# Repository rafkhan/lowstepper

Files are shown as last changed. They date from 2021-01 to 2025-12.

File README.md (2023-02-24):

# Lowstepper
```
██      ██████  ██     ██ ███████ ████████ ███████ ██████  ██████  ███████ ██████  
██     ██    ██ ██     ██ ██         ██    ██      ██   ██ ██   ██ ██      ██   ██ 
██     ██    ██ ██  █  ██ ███████    ██    █████   ██████  ██████  █████   ██████  
██     ██    ██ ██ ███ ██      ██    ██    ██      ██      ██      ██      ██   ██ 
███████ ██████   ███ ███  ███████    ██    ███████ ██      ██      ███████ ██   ██ 
                                                                                   

                  AN OPEN SOURCE EURORACK MODULE CREATED BY
 
      ▄ •▄  ▄▄▄· ▄· ▄▌.▄▄ ·  ▄· ▄▌ ▐ ▄ ▄▄▄▄▄ ▄ .▄▄▄▄ ..▄▄ · ▪  ·▄▄▄▄•▄▄▄ .▄▄▄  
▪     █▌▄▌▪▐█ ▀█▐█▪██▌▐█ ▀. ▐█▪██▌•█▌▐█•██  ██▪▐█▀▄.▀·▐█ ▀. ██ ▪▀·.█▌▀▄.▀·▀▄ █·
 ▄█▀▄ ▐▀▀▄·▄█▀▀█▐█▌▐█▪▄▀▀▀█▄▐█▌▐█▪▐█▐▐▌ ▐█.▪██▀▐█▐▀▀▪▄▄▀▀▀█▄▐█·▄█▀▀▀•▐▀▀▪▄▐▀▀▄ 
▐█▌.▐▌▐█.█▌▐█ ▪▐▌▐█▀·.▐█▄▪▐█ ▐█▀·.██▐█▌ ▐█▌·██▌▐▀▐█▄▄▌▐█▄▪▐█▐█▌█▌▪▄█▀▐█▄▄▌▐█•█▌
 ▀█▄▀▪·▀  ▀ ▀  ▀  ▀ •  ▀▀▀▀   ▀ • ▀▀ █▪ ▀▀▀ ▀▀▀ · ▀▀▀  ▀▀▀▀ ▀▀▀·▀▀▀ • ▀▀▀ .▀  ▀
```

LowStepper, a synth module by [Okay Synthesizer](https://okaysynthesizer.com/) <3

# LICENSE

This program is free software: you can redistribute it and/or modify
it under the terms of the GNU General Public License as published by
the Free Software Foundation, either version 3 of the License, or
(at your option) any later version.

This program is distributed in the hope that it will be useful,
but WITHOUT ANY WARRANTY; without even the implied warranty of
MERCHANTABILITY or FITNESS FOR A PARTICULAR PURPOSE.  See the
GNU General Public License for more details.

You should have received a copy of the GNU General Public License
along with this program.  If not, see <https://www.gnu.org/licenses/>.

------

Look, if you're considering selling this... go for it, but we would rather you call us up and collaborate. If you are going to sell it, please make your files available for the community to build on. That's all we ask :)

------

Maintained, with love, by [Okay Synthesizer](https://okaysynthesizer.com/) <3

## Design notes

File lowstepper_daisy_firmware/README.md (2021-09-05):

# lowstepper_daisy_firmware

## Author

<!-- Insert Your Name Here -->

## Description

<!-- Describe your example here -->

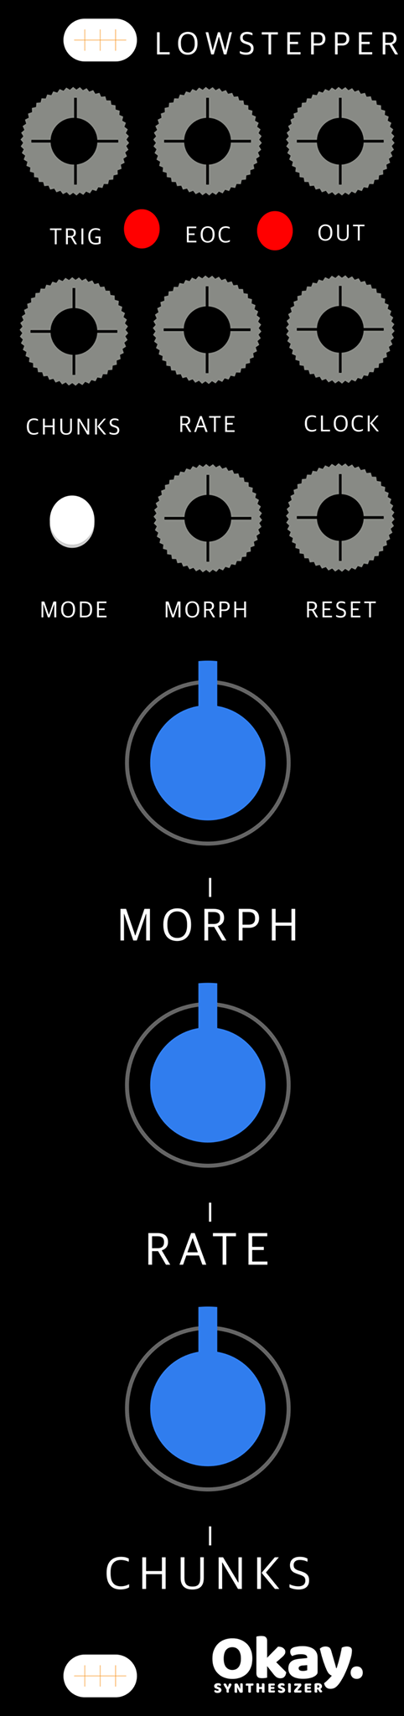
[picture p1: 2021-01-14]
lowstepper_wasm_demo/src/Lowstepper.png

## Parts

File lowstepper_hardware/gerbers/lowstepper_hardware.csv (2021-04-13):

Comment | Designator | Footprint | LCSC
1n | C2,C3,C4,C8,C9,C10 | Capacitor_SMD:C_0603_1608Metric_Pad1.08x0.95mm_HandSolder
47u | C1,C5 | Capacitor_SMD:C_0603_1608Metric_Pad1.08x0.95mm_HandSolder
10u | C6 | Capacitor_SMD:C_0603_1608Metric_Pad1.08x0.95mm_HandSolder
100n | C7 | Capacitor_SMD:C_0603_1608Metric_Pad1.08x0.95mm_HandSolder
XZM2CRKM2DGFBB45SCCB | D1,D2 | LED_XZM2CRKM2DGFBB45SCCB
Conn_01x20_Male | J18,J19 | Connector_PinHeader_2.54mm:PinHeader_1x20_P2.54mm_Vertical
Conn_01x20_Female | J20,J21 | Connector_PinSocket_2.54mm:PinSocket_1x20_P2.54mm_Vertical
PJ398SM-12 | J1,J2,J3,J4,J5,J6,J7,J9,J10,J11,J12,J13,J14,J15,J16,J17 | THONK_PJ398SM-12
Conn_02x08_Odd_Even | J8 | Connector_PinHeader_2.54mm:PinHeader_2x08_P2.54mm_Vertical
MMBT3904 | Q1,Q2,Q3,Q4,Q5,Q6 | Package_TO_SOT_SMD:SOT-23
470 | R16,R18,R47,R49 | Resistor_SMD:R_0603_1608Metric_Pad0.98x0.95mm_HandSolder
10K | R3,R7,R19,R34,R37,R40,R43,R46 | Resistor_SMD:R_0603_1608Metric_Pad0.98x0.95mm_HandSolder
1k | R2,R17,R48 | Resistor_SMD:R_0603_1608Metric_Pad0.98x0.95mm_HandSolder
10k | R20 | Resistor_SMD:R_0603_1608Metric_Pad0.98x0.95mm_HandSolder
3.3k | R1,R15,R21,R22,R32,R35,R38,R41,R44 | Resistor_SMD:R_0603_1608Metric_Pad0.98x0.95mm_HandSolder
100K | R4,R33,R36,R39,R42,R45 | Resistor_SMD:R_0603_1608Metric_Pad0.98x0.95mm_HandSolder
200k | R5,R9,R12,R23,R26,R29 | Resistor_SMD:R_0603_1608Metric_Pad0.98x0.95mm_HandSolder
100k | R6,R10,R13,R24,R27,R30 | Resistor_SMD:R_0603_1608Metric_Pad0.98x0.95mm_HandSolder
33k | R8,R11,R14,R25,R28,R31 | Resistor_SMD:R_0603_1608Metric_Pad0.98x0.95mm_HandSolder
10K | RV1,RV2,RV3,RV4,RV5,RV6 | Potentiometer_THT:Potentiometer_Alpha_RD901F-40-00D_Single_Vertical
SW_Push | SW1 | Button_Switch_SMD:SW_SPST_B3U-1000P
TL072 | U1 | Package_SO:SOIC-8_3.9x4.9mm_P1.27mm
MCP6004 | U2 | Package_SO:SOIC-14_3.9x8.7mm_P1.27mm
Teensy3.5 | U3 | teensy:Teensy35_36
LM4040DBZ-10 | U4 | Package_TO_SOT_SMD:SOT-23
MCP6002-xSN | U5,U6 | Package_SO:SOIC-8_3.9x4.9mm_P1.27mm

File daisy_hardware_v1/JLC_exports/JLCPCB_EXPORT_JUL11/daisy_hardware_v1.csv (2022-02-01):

Comment | Designator | Footprint | LCSC
47u | C1,C2 | Capacitor_SMD:CP_Elec_4x5.3
10u | C3,C13,C15 | Capacitor_SMD:CP_Elec_4x5.3
100n | C4,C14 | Capacitor_SMD:C_0603_1608Metric
1n | C5,C6,C7,C8,C9,C10,C11,C12 | Capacitor_SMD:C_0603_1608Metric
Conn_02x08_Odd_Even | J1 | Connector_PinHeader_2.54mm:PinHeader_2x08_P2.54mm_Vertical
PJ398SM-12 | J2,J3,J4,J5,J7,J8,J10,J11,J12,J13,J14,J15,J16,J17,J18,J19 | lowstepper_internal_footprint_lib:THONK_PJ398SM-12
Conn_01x18_Female | J20,J21 | Connector_PinSocket_2.54mm:PinSocket_1x18_P2.54mm_Vertical
Conn_01x18_Male | J6,J9 | Connector_PinHeader_2.54mm:PinHeader_1x18_P2.54mm_Vertical
MMBT3904 | Q2,Q3,Q5,Q6 | Package_TO_SOT_SMD:SOT-23
3.3k | R1,R2,R7,R9,R12,R18,R21 | Resistor_SMD:R_0603_1608Metric
100k | R10,R13,R19,R22,R25,R28,R31,R34,R37,R40,R43,R46 | Resistor_SMD:R_0603_1608Metric
200k | R24,R27,R30,R33,R36,R39,R42,R45 | Resistor_SMD:R_0603_1608Metric
33k | R26,R29,R32,R35,R38,R41,R44,R47 | Resistor_SMD:R_0603_1608Metric
10k | R3,R4,R6,R11,R14,R20,R23 | Resistor_SMD:R_0603_1608Metric
1k | R5 | Resistor_SMD:R_0603_1608Metric
10k | RV1,RV2,RV3,RV4,RV5,RV6,RV7,RV8 | Potentiometer_THT:Potentiometer_Alpha_RD901F-40-00D_Single_Vertical_CircularHoles
SW_SPDT | SW1,SW2 | lowstepper_internal_footprint_lib:dailywell_sw_spdt
RAF_DAISY_SEED_V1 | U1 | lowstepper_internal_footprint_lib:DAISY_SEED_OKAYSYNTH
LM1117-5.0 | U10 | Package_TO_SOT_SMD:SOT-223
TL072 | U2 | Package_SO:SOIC-8_3.9x4.9mm_P1.27mm
74HC4051 | U3,U4 | Package_SO:SOIC-16_3.9x9.9mm_P1.27mm
LM4040DBZ-10 | U5 | Package_TO_SOT_SMD:SOT-23
MCP6004 | U6,U7 | Package_SO:SO-14_3.9x8.65mm_P1.27mm
MCP6002-xSN | U8 | Package_SO:SOIC-8_3.9x4.9mm_P1.27mm
R-78E3.3-0.5 | U9 | Converter_DCDC:Converter_DCDC_RECOM_R-78E-0.5_THT

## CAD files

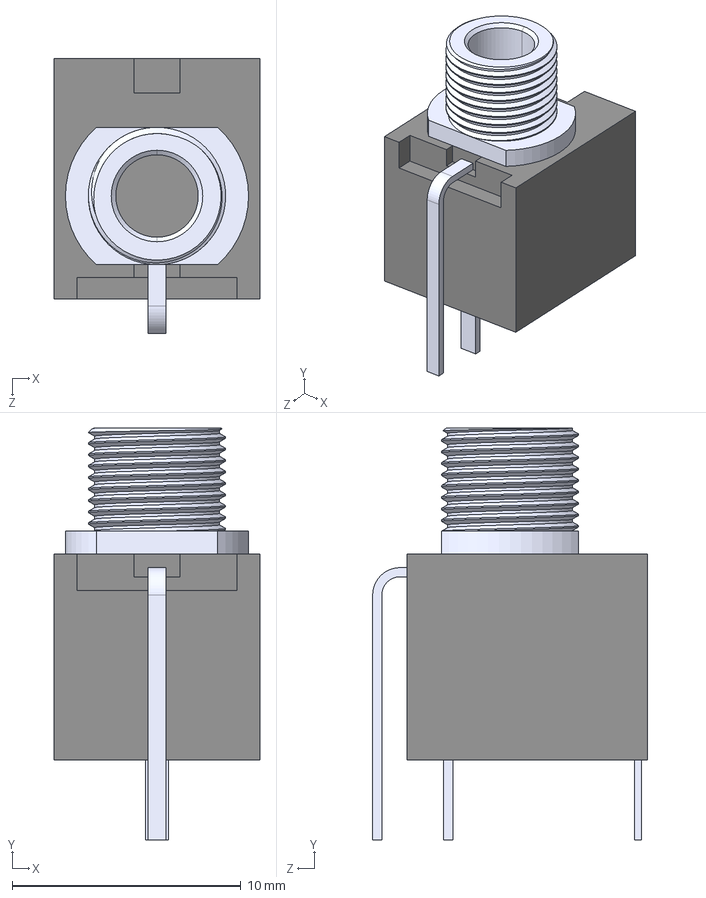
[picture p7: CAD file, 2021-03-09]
daisy_hardware_v1/external_libraries/PJ398SM-12/PJ398SM-12.step
9.00 x 18.0 x 12.0 mm

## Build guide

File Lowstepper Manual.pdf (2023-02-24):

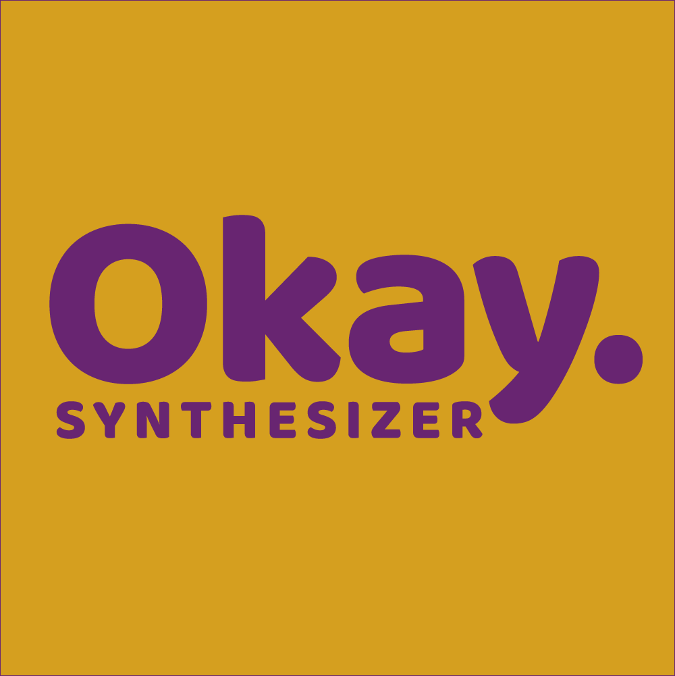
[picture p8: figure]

Hello, world.

Welcome to Okay Synthesizer, and thank you for purchasing a Lowstepper. It means the world to us to have you join the crew. We encourage you to do the maximum amount of damage possible with this module, and we promise that it is a substantial amount.

# Front Panel Overview

Both sides are identical, there are no normalled connections between them.

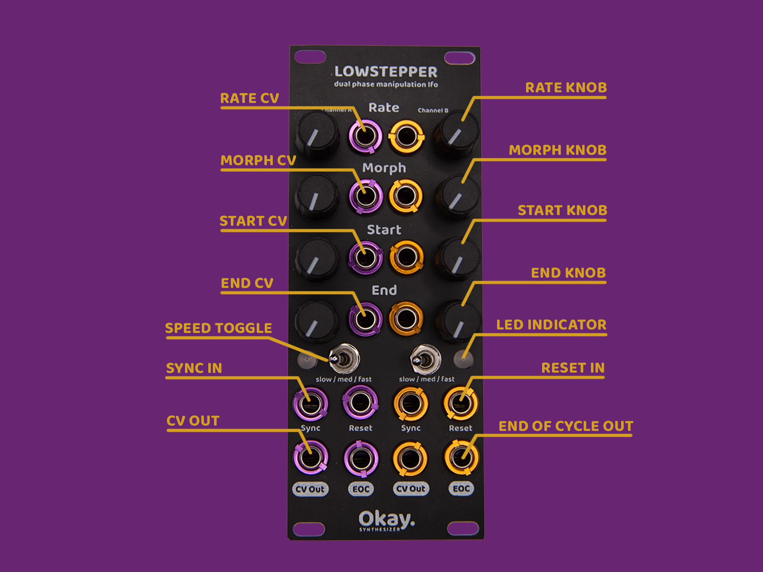
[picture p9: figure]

Rate: Change the speed of the LFO. The range of Rate changes based on the Speed Toggle. The rate will also change in fractional increments relative to the BPM, when sync is plugged in.

Morph: Warp the wave from sin, to triangle, to saw, to a slightly warped square.

Start: Move the start phase of the LFO from 0 - 100%. Will move in even increments when sync is plugged in.

End: Move the end phase of the LFO from 0 - 100%. Will move in even increments when sync is plugged in.

Speed Toggle: Switches between different ranges of speeds.

Sync In: Trigger input accepting 1/16th notes, will modify the behavior of Rate, Start and End when plugged in.

Reset In: Trigger input. Will instantly jump back to the start point of the LFO when a trigger is received.

CV Out: Main LFO output! Party time!

End of Cycle Out: Trigger output. Will output a trigger when the LFO reaches the end point.

# What the F**k is a “dual phase manipulation LFO” ?

I’m going to assume that you, the modular synthesizer owner, likely knows what an LFO is. It is a Low Frequency Oscillator. Which is described as an oscillator that moves below the frequency at which humans hear (20hz or so). In the case of Lowstepper, there are facilities for typical low frequency oscillations, as well as audible oscillations when Speed Toggle is set to Med or Fast.

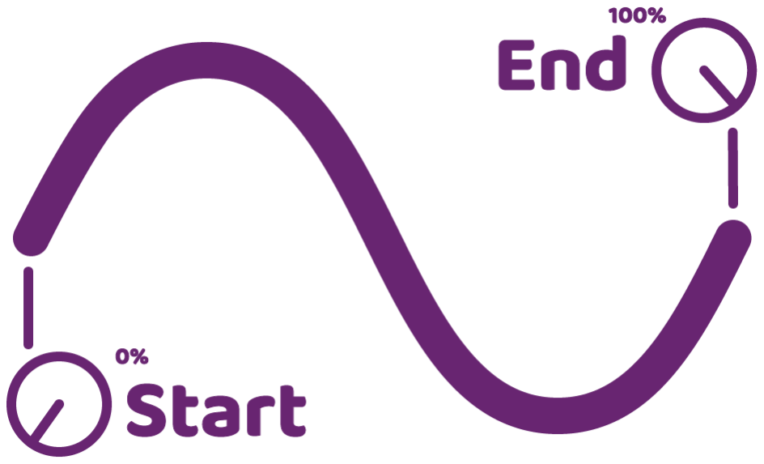
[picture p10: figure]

A completely unsuspecting sine wave….

The goal of lowstepper is to let you control the start and end position of a standard LFO
waveform, to create new wave shapes. You can push and pull the start and end points of the waves by turning the Start Knob and End Knob, and by using the corresponding Start CV and End CV controls beside them. When CV is passed into any controls, the knob acts as an offset.

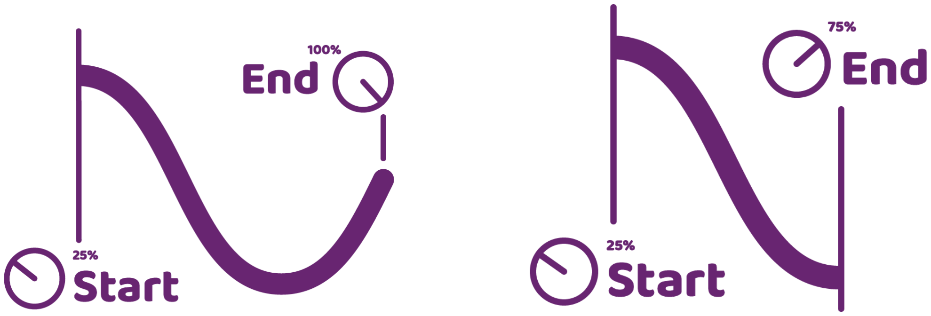
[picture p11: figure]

Left: Start point shifted 25%, end point left at 100% Right: Start and end point shifted to 25% and 75% respectively

When the end point is before the start, it will travel from the end to the start, effectively inverting the wave you started with

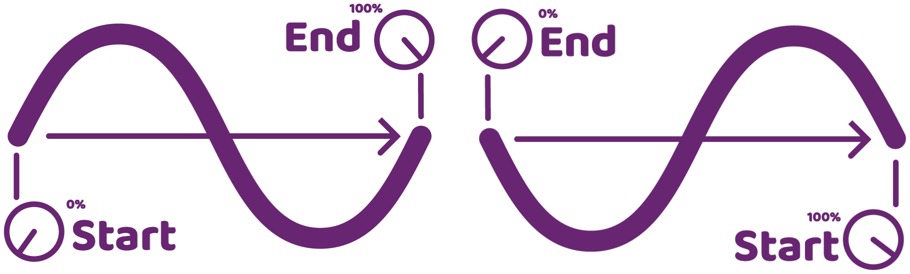
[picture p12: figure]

Left: Normal direction of travel Right: Inverted direction of travel

## Tech Specs

CV Output: 8v (-3.3 to 4.7 volts) the offset is intentional, so that the standard wave, and inverted wave shape is not 100% symmetrical, weird by design.
CV Inputs: +5v to -5v

EOC trigger output: +3.3v

## Firmware Update

Download the latest version of the firmware at https://okaysynthesizer.com/products/lowstepper in the Downloads section of the product description.

Visit https://electro-smith.github.io/Programmer/ and follow the on-screen instructions. Make sure you upload the correct firmware file from your computer before programming. Flashing the wrong firmware can result in unknown damages.

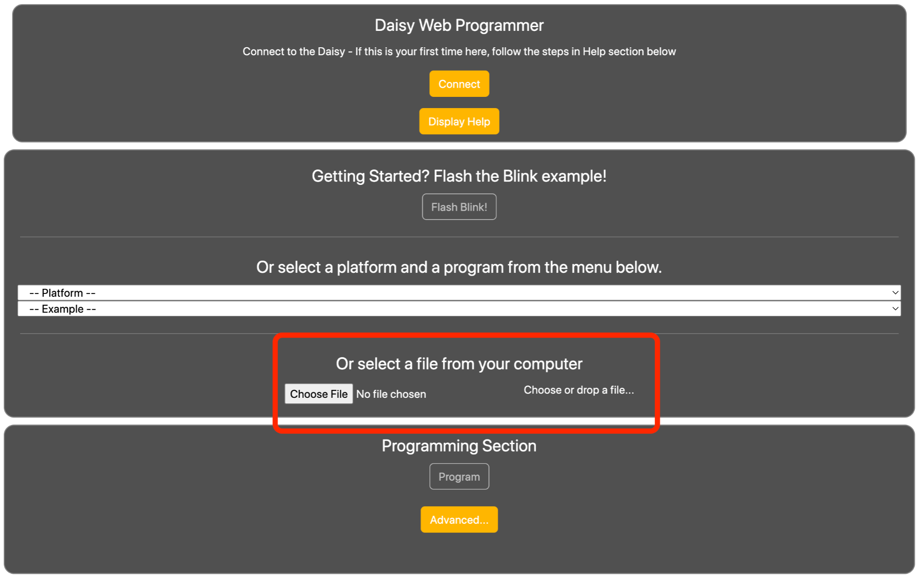
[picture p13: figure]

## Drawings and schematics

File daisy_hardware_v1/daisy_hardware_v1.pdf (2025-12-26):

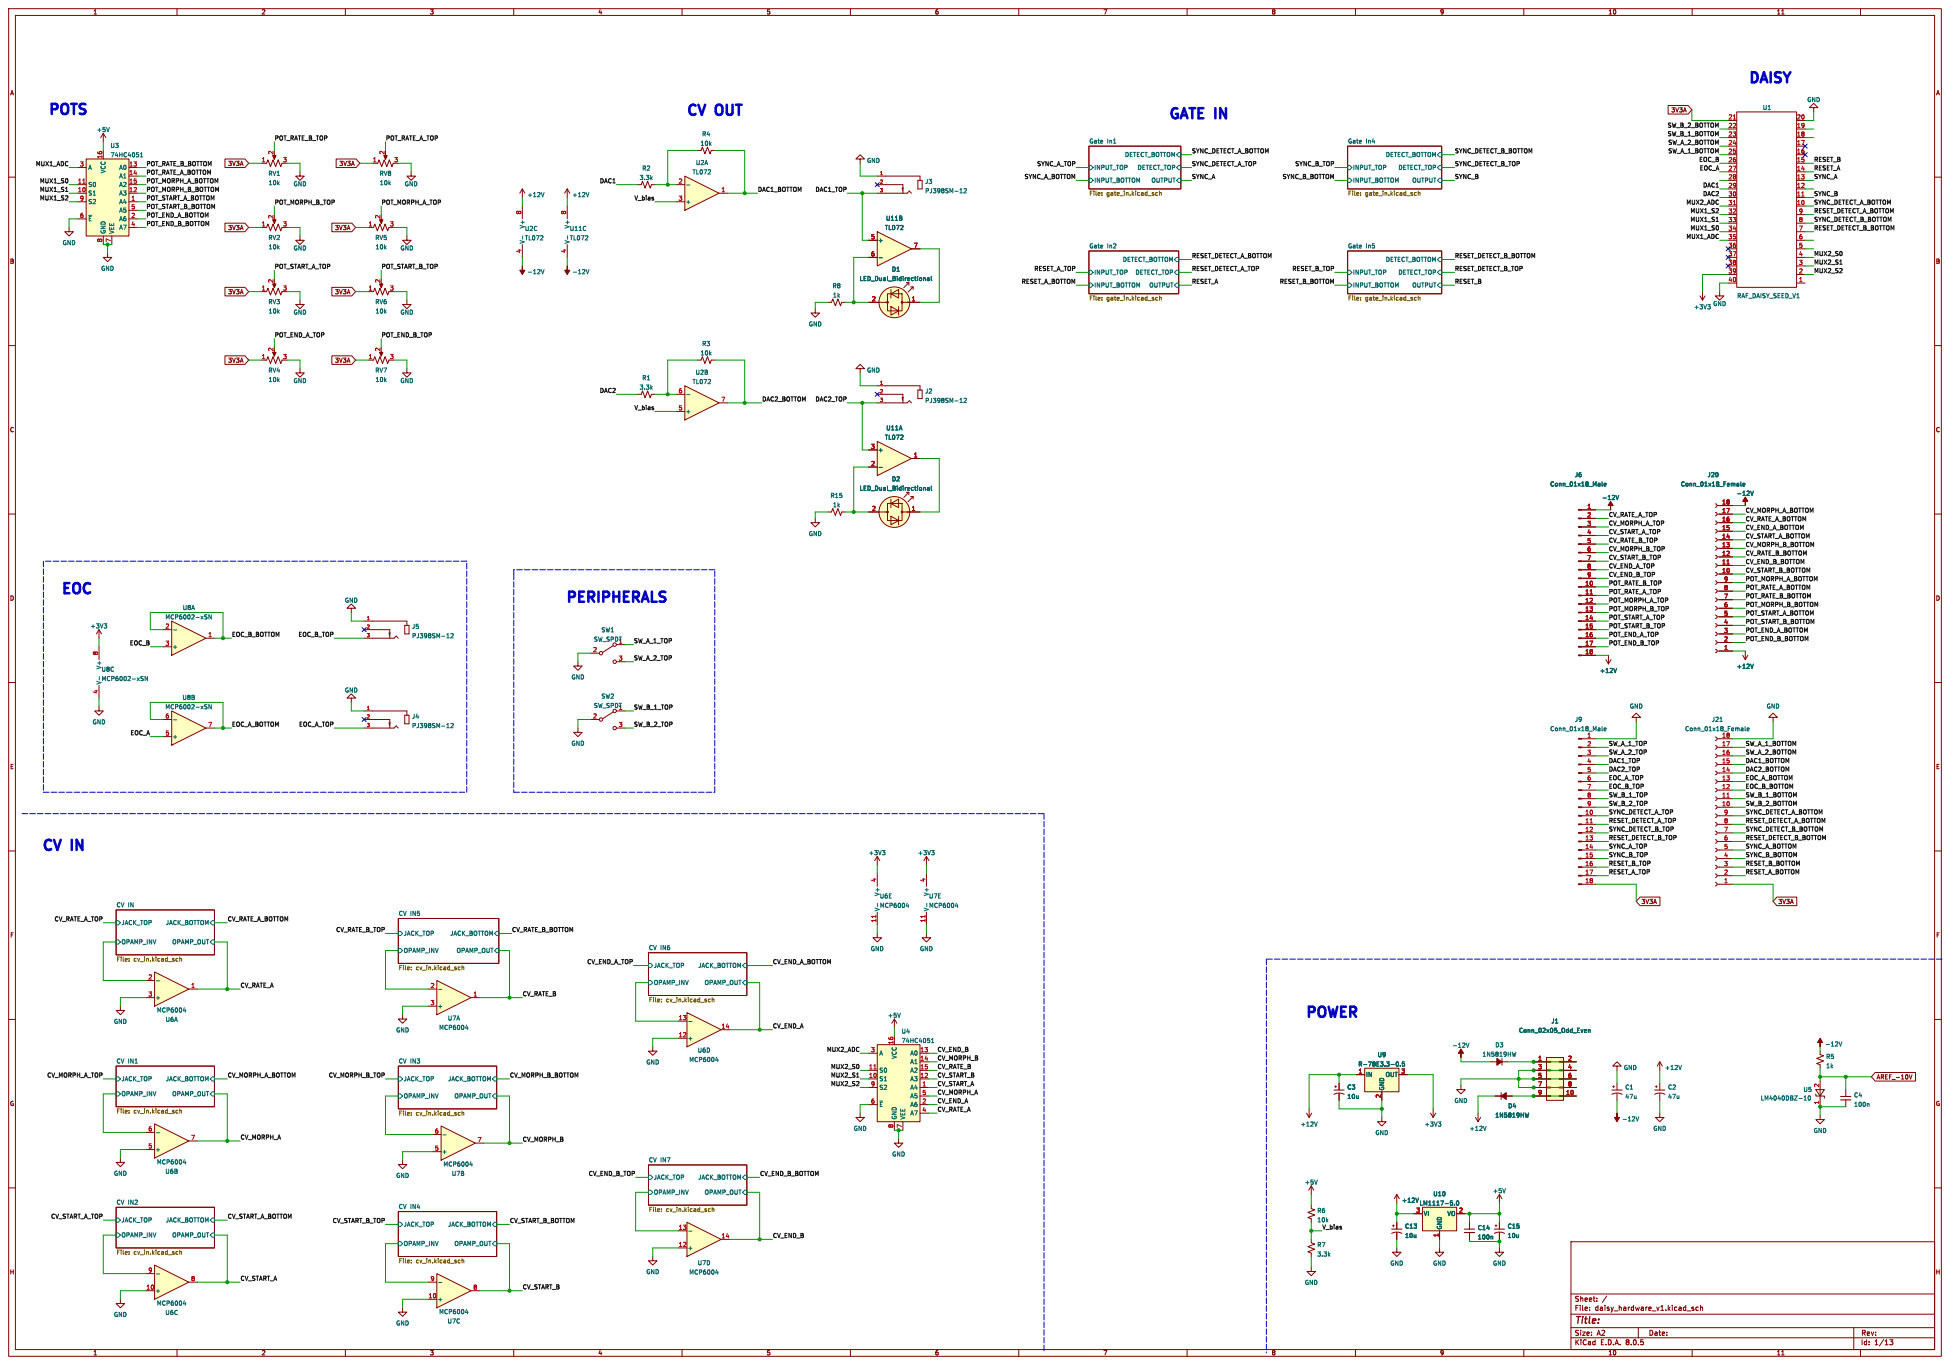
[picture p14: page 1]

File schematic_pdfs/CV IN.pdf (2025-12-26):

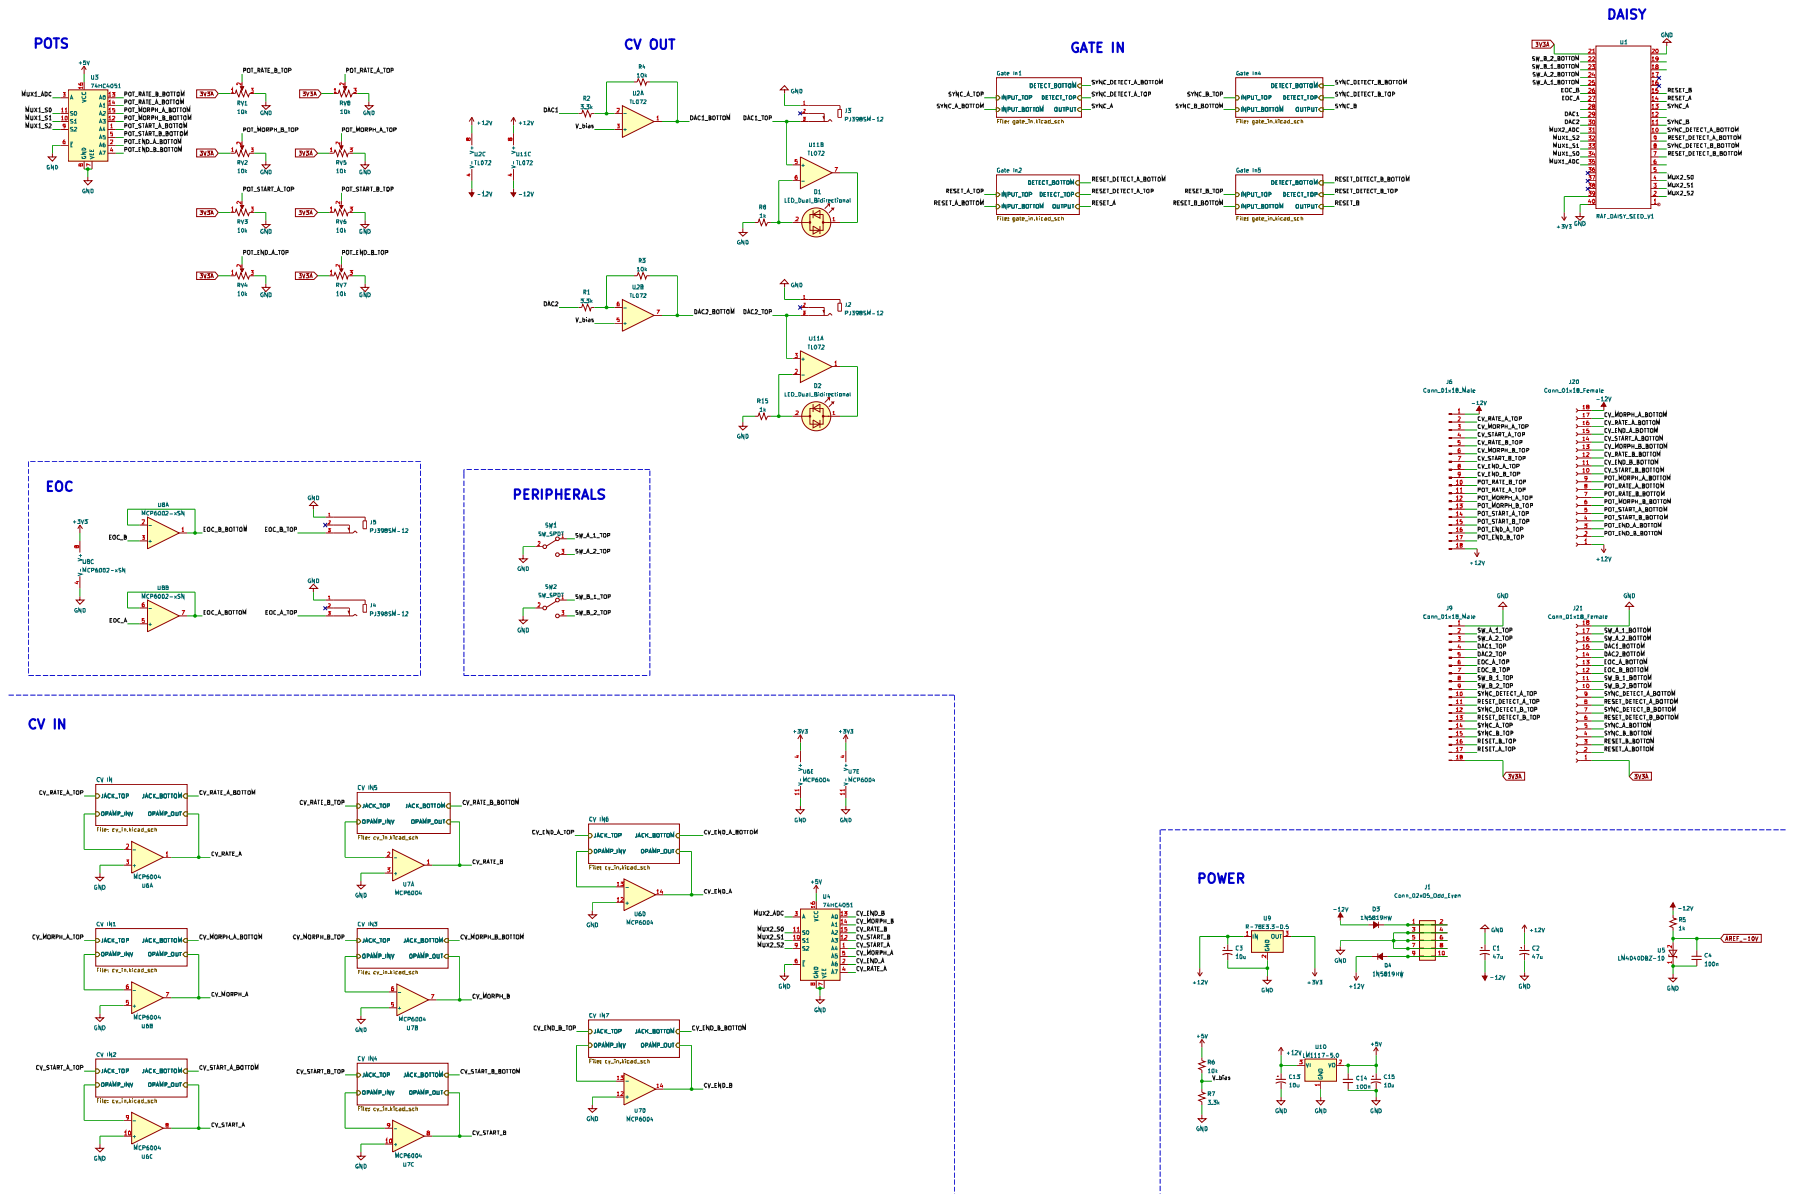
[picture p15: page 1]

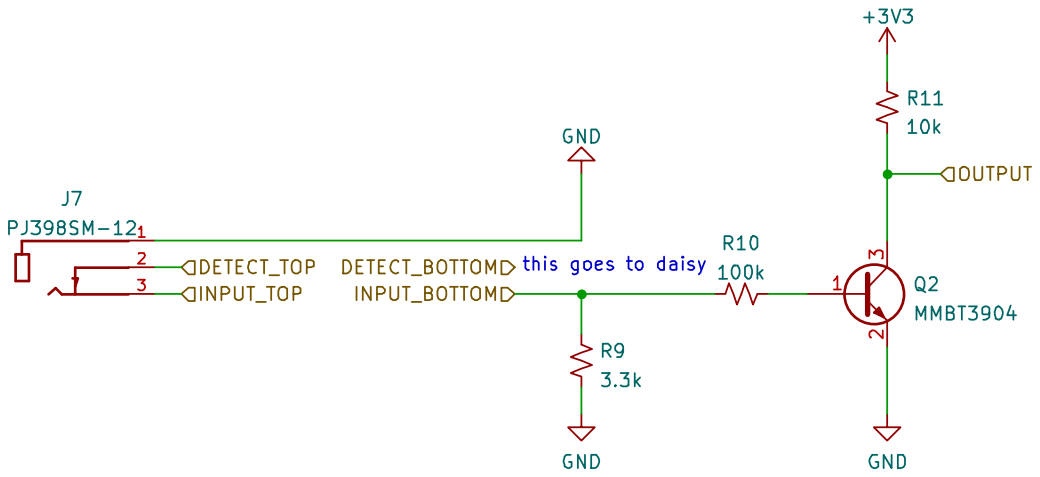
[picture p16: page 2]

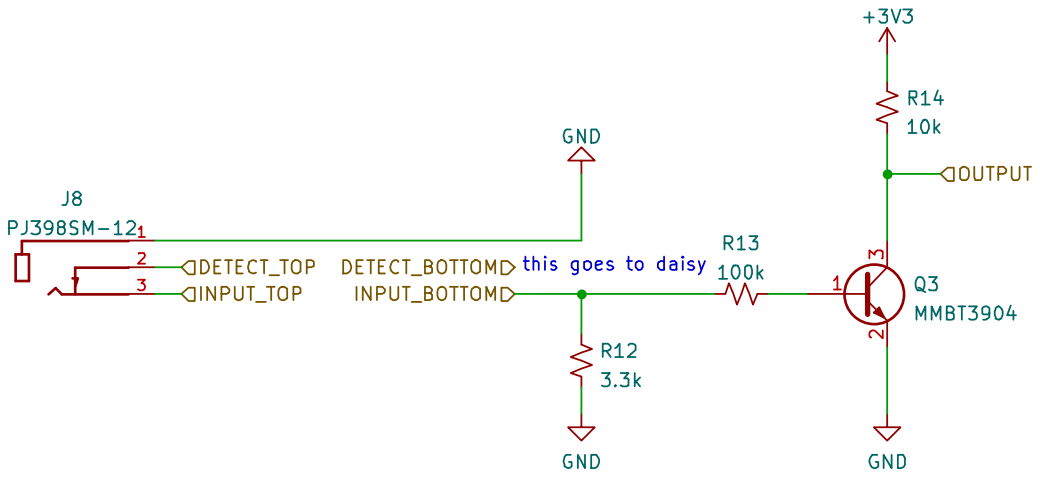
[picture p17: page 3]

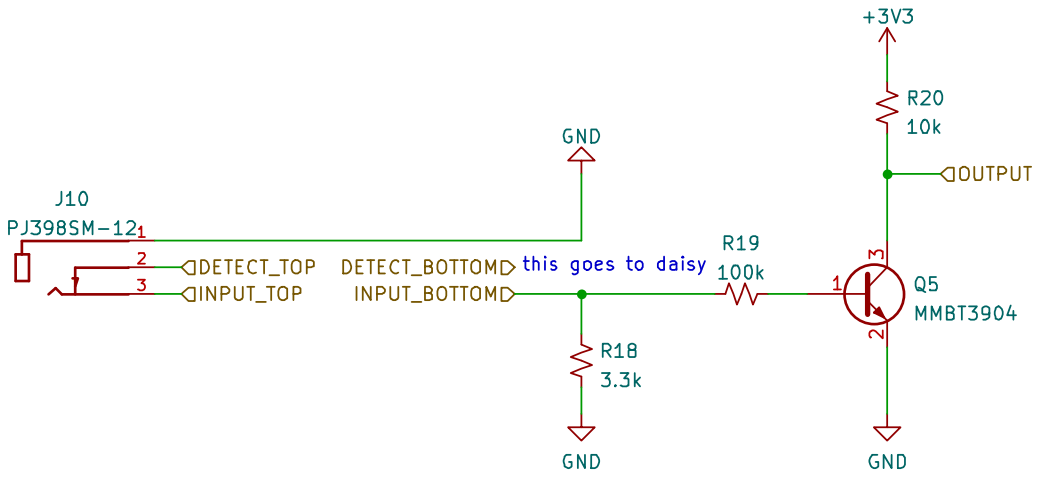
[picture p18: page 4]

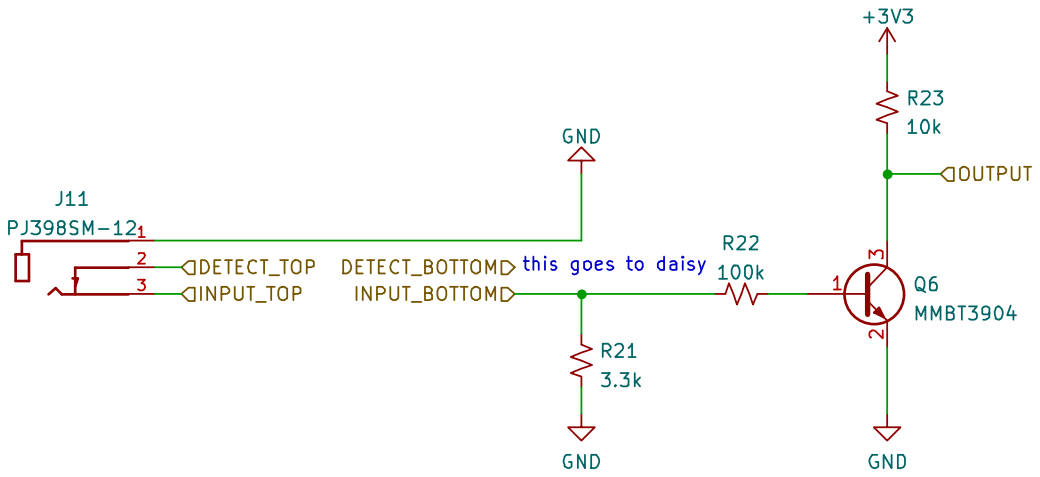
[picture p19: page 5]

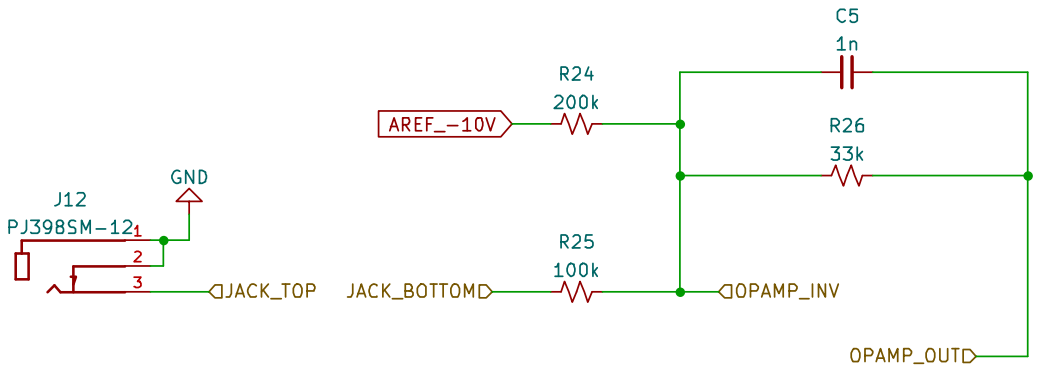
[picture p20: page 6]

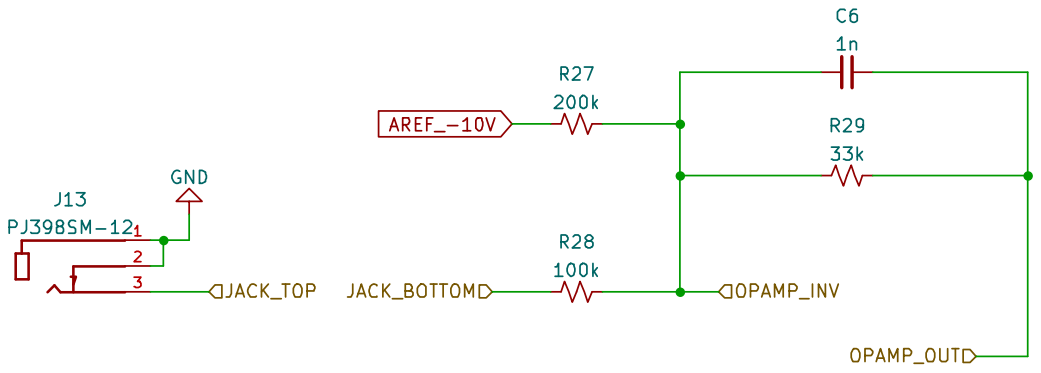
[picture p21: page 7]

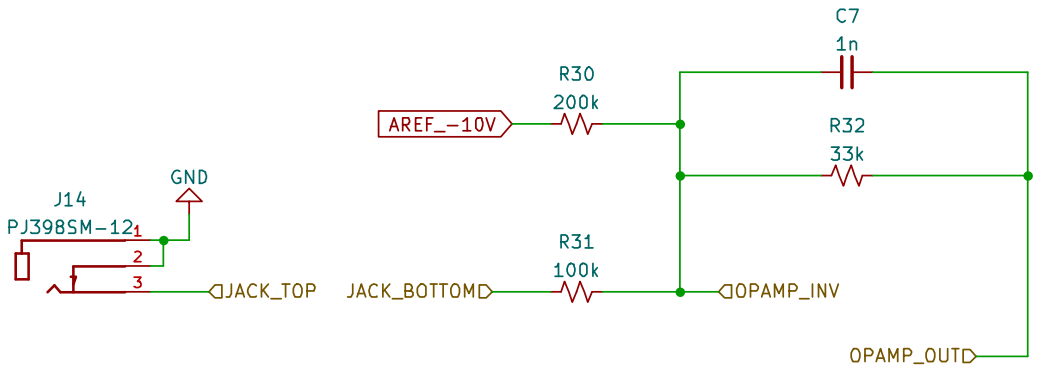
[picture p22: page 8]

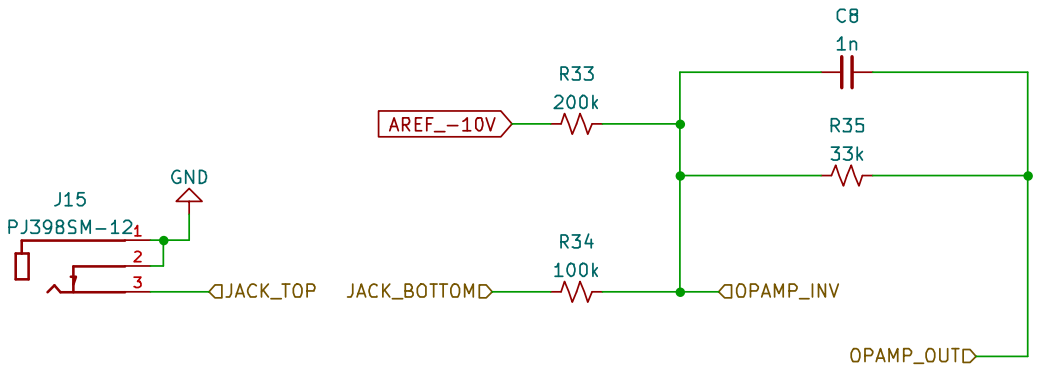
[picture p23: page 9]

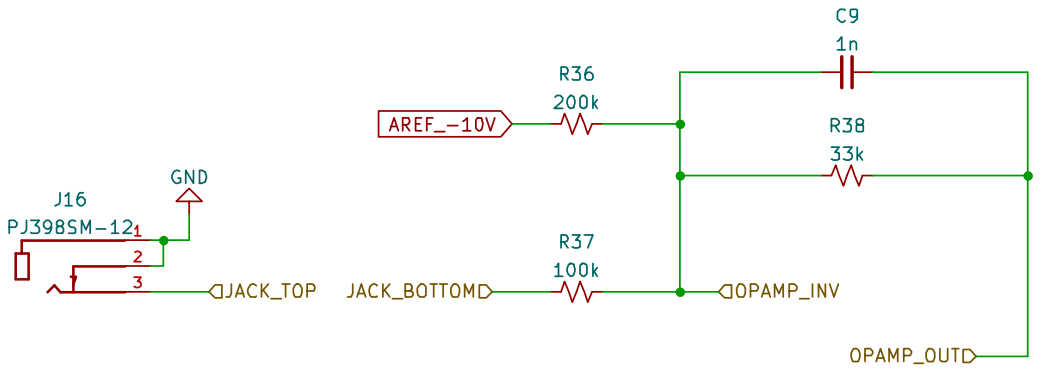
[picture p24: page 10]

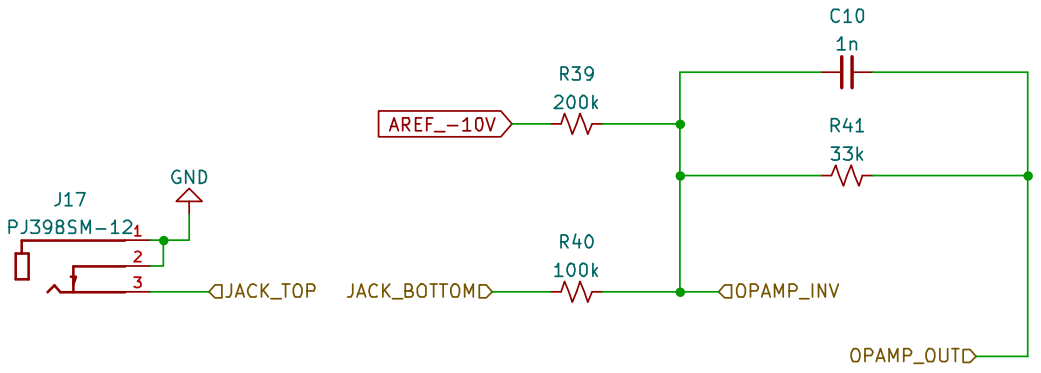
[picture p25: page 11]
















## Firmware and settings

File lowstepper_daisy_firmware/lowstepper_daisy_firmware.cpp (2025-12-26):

#include <cstddef>
#include <cmath>
#include <limits.h>

#include "daisy_seed.h"
#include "daisysp.h"

#include "lowstepper/LowStepperLfo.h"
#include "lowstepper/LowStepperAdsr.h"
#include "lowstepper/AverageBuffer.h"
#include "lowstepper/SyncManager.h"
#include "lowstepper/util.h"

#include "hardware/GateInput.h"
#include "hardware/GateOutput.h"
#include "hardware/LSSwitch.h"

#define DEBUG_LS 0
#define AUDIO_BLOCK_SIZE 1

// PIN MAPPING
#define MUX1ADC 28
#define MUX1S0 27
#define MUX1S1 26
#define MUX1S2 25

#define MUX2ADC 24
#define MUX2S0 3
#define MUX2S1 2
#define MUX2S2 1

#define PIN_SYNC_A 12	
#define PIN_SYNC_DETECT_A 9
#define PIN_RESET_A 13	
#define PIN_RESET_DETECT_A 8

#define PIN_SYNC_B 10
#define PIN_SYNC_DETECT_B 7
#define PIN_RESET_B 14
#define PIN_RESET_DETECT_B 6

#define PIN_SWITCH_A_1 17
#define PIN_SWITCH_A_2 18
#define PIN_SWITCH_B_1 16
#define PIN_SWITCH_B_2 15

#define PIN_EOC_A 20
#define PIN_EOC_B 19

using namespace daisy;
using namespace daisysp;

// hardware objects
static DaisySeed hw;
GateInput syncA;
GateInput resetA;
GateInput syncB;
GateInput resetB;
GateOutput eocA;
GateOutput eocB;
LSSwitch switchA1;
LSSwitch switchA2;
LSSwitch switchB1;
LSSwitch switchB2;

// Config
float sampleRate;

// Internal objects
const size_t channelCount = 2;
LowStepperOutput lastOutputA { 0, 0, false };
LowStepperOutput lastOutputB { 0, 0, false };
LowStepperLfo *lfoA;
LowStepperLfo *lfoB;
LowStepperAdsr *adsrA;
SyncManager syncManagerA;
SyncManager syncManagerB;

// ADC Input stuff
int adcCycleCounter = 0;
float potInputs[8];
float cvInputs[8];

// Output values
float cvCh1 = 0;
float cvCh2 = 0;

// Metro for development
Metro tick;
bool metroValue = false;

// TODO: Fix all of these mappings...
float getRateAInput() {
	return combinePotAndCv(potInputs[1], cvInputs[5]);
}

float getMorphAInput() {
	return combinePotAndCv(potInputs[0], cvInputs[7]);
}

float getStartAInput() {
	return combinePotAndCv(potInputs[4], cvInputs[6], true);
}

float getLengthAInput() {
	return combinePotAndCv(potInputs[6], cvInputs[0], true);
}

float getRateBInput() {
	return combinePotAndCv(potInputs[2], cvInputs[4]);
}

float getMorphBInput() {
	return combinePotAndCv(potInputs[3], cvInputs[1]);
}

float getStartBInput() {
	return combinePotAndCv(potInputs[5], cvInputs[2], true);
}

float getLengthBInput() {
	return combinePotAndCv(potInputs[7], cvInputs[3], true);
}

void initAdc() {
	AdcChannelConfig adc[2];
	adc[0].InitMux(hw.GetPin(MUX1ADC), 8, hw.GetPin(MUX1S0), hw.GetPin(MUX1S1), hw.GetPin(MUX1S2));
	adc[1].InitMux(hw.GetPin(MUX2ADC), 8, hw.GetPin(MUX2S0), hw.GetPin(MUX2S1), hw.GetPin(MUX2S2));
	hw.adc.Init(adc, 2);
	hw.adc.Start();
}

void initGpioOut() {
	eocA.init(&hw, sampleRate, 1, PIN_EOC_A);
	eocB.init(&hw, sampleRate, 1, PIN_EOC_B);
}

void initGpioIn() {
	syncA.init(&hw, PIN_SYNC_A, PIN_SYNC_DETECT_A);
	resetA.init(&hw, PIN_RESET_A, PIN_RESET_DETECT_A);
	syncB.init(&hw, PIN_SYNC_B, PIN_SYNC_DETECT_B);
	resetB.init(&hw, PIN_RESET_B, PIN_RESET_DETECT_B);

	switchA1.init(&hw, PIN_SWITCH_A_1);
	switchA2.init(&hw, PIN_SWITCH_A_2);
	switchB1.init(&hw, PIN_SWITCH_B_1);
	switchB2.init(&hw, PIN_SWITCH_B_2);
}

void initDac() {
	DacHandle::Config cfg;
	cfg.bitdepth = DacHandle::BitDepth::BITS_12;
	cfg.buff_state = DacHandle::BufferState::ENABLED;
	cfg.mode = DacHandle::Mode::POLLING;
	cfg.chn = DacHandle::Channel::BOTH;
	hw.dac.Init(cfg);
	hw.dac.WriteValue(DacHandle::Channel::BOTH, 0);
	hw.dac.WriteValue(DacHandle::Channel::ONE, 0); // CV0
	hw.dac.WriteValue(DacHandle::Channel::TWO, 0); // CV1
}

void initSync(float sampleRate) {
	syncManagerA.init(sampleRate);
	syncManagerB.init(sampleRate);
}

void readAdc() {
	for(int i = 0; i < 8; i++) {
		float potValue = fmin(1, fmax(0, (1.0 - hw.adc.GetMuxFloat(0, i))));
		potInputs[i] = 1.0 - pow(potValue - 1.0, 2);
		cvInputs[i] = 1.0 - hw.adc.GetMuxFloat(1, i);
	}
}

void writeDac() {
	// Not sure why 1.1 solved this flattening issue
	// TODO: investigate for next module
	uint16_t y1 = mapFFII(cvCh1 * -1.0, -1.1, 1.1, 0, 4095);
	uint16_t y2 =	mapFFII(cvCh2 * -1.0, -1.1, 1.1, 0, 4095);

	// accidentally reversed??
	hw.dac.WriteValue(DacHandle::Channel::TWO, y1);
	hw.dac.WriteValue(DacHandle::Channel::ONE, y2);
}

void readGpioIn() {
	syncA.readHardware();
	resetA.readHardware();
	syncB.readHardware();
	resetB.readHardware();

	switchA1.readHardware();
	switchA2.readHardware();
	switchB1.readHardware();
	switchB2.readHardware();
}


void AudioCallback(AudioHandle::InterleavingInputBuffer in,
									 AudioHandle::InterleavingOutputBuffer out,
									 size_t size) {
	if(tick.Process()) {
		metroValue = true;
	}

	readAdc();
	readGpioIn();

	for (size_t n = 0; n < size; n += 2) {
		if(!lfoA || !lfoB || !adsrA) {
			break;
		}
		// TODO refactor this to not be duplicated...
		bool useSyncA = syncManagerA.tick(syncA.triggerCheck());
		float avgBpmValueA = syncManagerA.getBpm();
		// bool useFastModeA = !switchA2.isOn();

		bool useSyncB = syncManagerB.tick(syncB.triggerCheck());
		float avgBpmValueB = syncManagerB.getBpm();


		LowStepperLfoMode modeA = LowStepperLfoMode::MEDIUM;
		if (!switchA1.isOn()) {
			modeA = LowStepperLfoMode::SLOW;
		}
		
		if (!switchA2.isOn()) {
			modeA = LowStepperLfoMode::FAST;
		}

		LowStepperLfoMode modeB = LowStepperLfoMode::MEDIUM;
		if (!switchB1.isOn()) {
			modeB = LowStepperLfoMode::SLOW;
		}
		
		if (!switchB2.isOn()) {
			modeB = LowStepperLfoMode::FAST;
		}

		LowStepperInput inputA;
		inputA.phase = lastOutputA.phase;
		inputA.frequency = LowStepperLfo::mapRateInputToFrequency(getRateAInput(), useSyncA, modeA, avgBpmValueA);
		inputA.morph = LowStepperLfo::mapMorphInput(getMorphAInput());
		inputA.start = LowStepperLfo::mapStartInput(getStartAInput(), useSyncA);
		inputA.end = LowStepperLfo::mapLengthInput(getLengthAInput(), useSyncA);
		inputA.shouldReset = resetA.triggerCheck();

		LowStepperInput inputB;
		inputB.phase = lastOutputB.phase;
		inputB.frequency = LowStepperLfo::mapRateInputToFrequency(getRateBInput(), useSyncB, modeB, avgBpmValueB);
		inputB.morph = LowStepperLfo::mapMorphInput(getMorphBInput());
		inputB.start = LowStepperLfo::mapStartInput(getStartBInput(), useSyncB);
		inputB.end = LowStepperLfo::mapLengthInput(getLengthBInput(), useSyncB);
		inputB.shouldReset = resetB.triggerCheck();
 
		lastOutputA = lfoA->tick(inputA);
		lastOutputB = lfoB->tick(inputB);

		if(lastOutputA.eocGateHigh) {
			eocA.setGateHigh(0);
		}

		if(lastOutputB.eocGateHigh) {
			eocB.setGateHigh(0);
		}

		eocA.tick();
		eocB.tick();

		// Copy data out of application to send to DAC
		cvCh1 = lastOutputA.cvOutput;
		cvCh2 = lastOutputB.cvOutput;

		// Don't do anything on audio output
		out[n] = 0;
		out[n + 1] = 0;
	}
}

int main(void) {
	// Init Daisy
	hw.Configure();
	hw.Init();
	hw.SetAudioSampleRate(SaiHandle::Config::SampleRate::SAI_48KHZ);
	sampleRate = hw.AudioSampleRate();

	tick.Init(2.f, sampleRate);

#if DEBUG_LS
  hw.StartLog();
	System::Delay(100);
#endif

	initDac();
	initAdc();
	initGpioOut();
	initGpioIn();
	initSync(sampleRate);

	lfoA = new LowStepperLfo(sampleRate);
	lfoB = new LowStepperLfo(sampleRate);
	adsrA = new LowStepperAdsr(sampleRate);

	hw.SetAudioBlockSize(AUDIO_BLOCK_SIZE);
	hw.StartAudio(AudioCallback);

	hw.adc.GetMuxFloat(0, 0);
 
	for (;;)
	{
		writeDac();

#if DEBUG_LS
		if(metroValue) {
			metroValue = false;
			hw.PrintLine("%f", potInputs[4]);
		}
#endif
	}

}

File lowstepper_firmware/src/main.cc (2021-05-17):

#include <Arduino.h>
#include <cmath>

#include "ui/UI.h"
#include "lowstepper.h"

#define DEBUG_POT_VALUES 1
#define DEBUG_CV_IN_VALUES 0
#define DEBUG_TRIGGER_IN 0
#define DEBUG_TRIGGER_OUT 0
#define DEBUG_CV_OUT 0

// Timer related stuff
// IntervalTimer main_timer;

// static constexpr uint32_t CORE_ISR_FREQ = 3000U; // how much faster can I make this? lmao
// static constexpr uint32_t CORE_TIMER_RATE = (1000000UL / CORE_ISR_FREQ);

// void FASTRUN main_timer_ISR()
// {
//   // MAIN CODE HERE
// }

void setup()
{
  analogWriteResolution(12);

  // power alive light
  pinMode(13, OUTPUT);
  digitalWrite(13, HIGH);

  getUI()->init();

  // main_timer.begin(main_timer_ISR, CORE_TIMER_RATE);
}

#if DEBUG_CV_OUT
float debug_cv_phase = 0.0;
elapsedMicros debug_cv_usec = 0;
#endif

#if DEBUG_TRIGGER_OUT
uint32_t debug_eoc_a_time = millis();
uint32_t debug_eoc_b_time = millis();
#endif

void loop()
{
  // Block interrupts when reading hardware I/O
    UI *ui = getUI();
    ui->scan();
  // allow interrupts again

/********************************************
 * DEBUG CODE BELOW
 * ENABLE VIA FLAGS AT THE TOP OF THIS FILE 
 ********************************************/
#if DEBUG_POT_VALUES
      Serial.printf(
          "POTS:\tRATE_A: %d \t RATE_B: %d \t MORPH_A: %d \t MORPH_B: %d \t CHUNKS_A: %d \t CHUNKS_B: %d\n",
          ui->potInRateA->getValue(),
          ui->potInRateB->getValue(),
          ui->potInMorphA->getValue(),
          ui->potInMorphB->getValue(),
          ui->potInChunksA->getValue(),
          ui->potInChunksB->getValue());
#endif

#if DEBUG_CV_IN_VALUES
  Serial.printf(
      "CV:\tRATE_A: %d \t RATE_B: %d \t MORPH_A: %d \t MORPH_B: %d \t CHUNKS_A: %d \t CHUNKS_B: %d\n",
      ui->cvInRateA->getValue(),
      ui->cvInRateB->getValue(),
      ui->cvInMorphA->getValue(),
      ui->cvInMorphB->getValue(),
      ui->cvInChunksA->getValue(),
      ui->cvInChunksB->getValue());
#endif

#if DEBUG_TRIGGER_IN
  Serial.printf(
      "TRIG_A: %d/%d,\t CLK_A: %d/%d,\t RST_A: %d/%d\t",
      ui->trigInA->isCablePluggedIn(),
      ui->trigInA->isGateHigh(),
      ui->clockInA->isCablePluggedIn(),
      ui->clockInA->isGateHigh(),
      ui->resetInA->isCablePluggedIn(),
      ui->resetInA->isGateHigh());

  Serial.printf(
      "TRIG_B: %d/%d,\t CLK_B: %d/%d,\t RST_B: %d/%d\n",
      ui->trigInB->isCablePluggedIn(),
      ui->trigInB->isGateHigh(),
      ui->clockInB->isCablePluggedIn(),
      ui->clockInB->isGateHigh(),
      ui->resetInB->isCablePluggedIn(),
      ui->resetInB->isGateHigh());
#endif

#if DEBUG_CV_OUT
  double y = sin(debug_cv_phase);
  float valA = y * 2000.0 + 2050.0;
  float valB = y * -2000.0 + 2050.0;
  ui->cvOutA->write(valA);
  ui->cvOutB->write(valB);
  debug_cv_phase = debug_cv_phase + 0.02;
  if (debug_cv_phase >= TWO_PI)
  {
    debug_cv_phase = 0;
  }
  while (debug_cv_usec < 500)
  {
    // wait
  }
  debug_cv_usec = debug_cv_usec - 500;
#endif

#if DEBUG_TRIGGER_OUT
  if ((millis() - debug_eoc_a_time) > 1000)
  {
    ui->eocA->setHighForDuration(millis(), 500);
    debug_eoc_a_time = millis();
  }

  if ((millis() - debug_eoc_b_time) > 500)
  {
    ui->eocB->setHighForDuration(millis(), 250);
    debug_eoc_b_time = millis();
  }

  ui->eocA->tick(millis());
  ui->eocB->tick(millis());
#endif

  selectaRunThaRecord();
}

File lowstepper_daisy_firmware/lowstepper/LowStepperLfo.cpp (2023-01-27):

#include <stdint.h>
#include <math.h>
#include "LowStepperLfo.h"
#include "util.h"


/**
 * All of the following functions take a phase input from 0 - TWO_PI
 * and return a value from -1 to 1.
 * 
 * lmao math
 */
float LowStepperLfo::triangle(float phase) {
  //REALLY DUMB CODE, NEED TO BE OPTIMIZED!

  if (phase <= PI * 0.5) //FIRST QUARTER
  {
    return 2 + ( -1 * (((PI - phase * 2) + PI) / PI) ); //GO DOWN!
  }

  if(phase >= PI * 1.5) //FOURTH QUARTER
  {
    return -1 + ( -1 * (((TWO_PI - phase * 2) + PI) / PI) ) ; //GO DOWN TOO!
  } 
  
  //SECOND AND THIRD QUARTER 
  return 1 + ( -1 * ((phase*2 - PI) / PI)); //GO UP!

}

float LowStepperLfo::ramp(float phase) {
  return -1 * ((phase - PI) / PI);
}

float LowStepperLfo::saw(float phase) {
  if (phase <= PI) {
    return phase / PI;
  }

  return ((phase - PI) / PI) - 1;
}

float LowStepperLfo::square(float phase) {
  if (phase >= PI)
  {
    return -1;
  }
  return 1;
}

// TODO: stop computing the same thing more than once!!!
// TODO: CLEAN UP THIS LOGIC.
float LowStepperLfo::getMorphedOutput(float morphPosition, float phase) {
  double newMorph;
  if(morphPosition <= 0.33) {
    newMorph = mapFFFF(morphPosition, 0, 0.33, 0, 1);
    return sin(phase) + (newMorph * (triangle(phase) - sin(phase)));
  } else if(morphPosition > 0.33 && morphPosition <= 0.66) {
    newMorph = mapFFFF(morphPosition, 0.34, 0.66, 0, 1);
    return triangle(phase) + (newMorph * (saw(phase) - triangle(phase)));
  } else {
    newMorph = mapFFFF(morphPosition, 0.67, 1, 0, 0.8); // NOT 0-1 to avoid square wave
    return saw(phase) + (newMorph * (square(phase) - saw(phase)));
  }
}

float LowStepperLfo::mapRateInputToFrequency(float input, bool enableSync, LowStepperLfoMode mode, float bpm) {
  if(enableSync) {
    float mult = 0.5f;
    if(mode == LowStepperLfoMode::MEDIUM) {
      mult = 8;
    }

    if(mode == LowStepperLfoMode::FAST) {
      mult = 64;
    }

    float maxFreq = (bpm / 60.0f) * mult;
    float divisor = floor(mapFFFF(input, 0, 1, 16, 1)); // will never actually go to 17?
    return maxFreq / divisor;
  } else {
    // non-linear curve here.
    float min = 0.0001f;
    float max = 2.0f;

    if(mode == LowStepperLfoMode::MEDIUM) {
      min = 1.0f;
      max = 20.0f;
    }

    if(mode == LowStepperLfoMode::FAST) {
      min = 18.0f;
      max = 80.0f;
    }

    return mapFFFF(pow(input, 2), 0, 1, min, max);
  }
}

float LowStepperLfo::mapMorphInput(float input) {
  return input; // doesn't need to be mapped to any fn
}

float getDividerFromPosition(float input) {
    int position = floor(mapFFFF(input, 0, 1, 0, 9));
    float div = 1; 

    // LOL fix this wtf raf were you high?
    if(position == 0) {
      div = 0;
    }

    if(position == 1) {
      div = 0.125;
    }

    if(position == 2) {
      div = 0.25;
    }

    if(position == 3) {
      div = 0.375;
    }

    if(position == 4) {
      div = 0.5;
    }

    if(position == 5) {
      div = 0.625;
    }

    if(position == 6) {
      div = 0.75;
    }

    if(position == 7) {
      div = 0.875;
    }

    if(position == 8) {
      div = 1;
    }

    return div;
}


float LowStepperLfo::mapLengthInput(float input, bool enableSync) {
  if(enableSync) {
    return getDividerFromPosition(input);
  }

  return input;
}

float LowStepperLfo::mapStartInput(float input, bool enableSync)
{
  if(enableSync) {
    return getDividerFromPosition(input);
  }

  return input;
}

LowStepperLfo::LowStepperLfo(float sampleRate) {
  this->sampleRate = sampleRate;
  this->sampleLength = (1.0f/sampleRate)*1000000.0f;
}

LowStepperOutput LowStepperLfo::tick(LowStepperInput input) {
    float phaseIncrement = (this->sampleLength / (1000000.0 / input.frequency)) * TWO_PI;

    float start = input.start;
    float end = input.end;
    float startPhase;
    float endPhase;
    float phase;

    LowStepperOutput output;
    output.eocGateHigh = false;

    startPhase = TWO_PI * start;
    endPhase = TWO_PI - (TWO_PI * (1 - end));

    // TODO implement range to cancel out start/end
    if(start < end && end - start > 0.01) {
      phase = input.phase + phaseIncrement;

      if (phase > endPhase) {
        phase = startPhase + (phase - endPhase);
        output.eocGateHigh = true;
      }
    } else if(start > end && start - end > 0.01) {
      phase = input.phase - phaseIncrement;

      if (phase < endPhase) {
        phase = startPhase + (phase - endPhase);
        output.eocGateHigh = true;
      }
    } else {
      phase = input.phase;
    }

    if(input.shouldReset) {
      phase = startPhase;
    }

    output.cvOutput = getMorphedOutput(input.morph, phase);
    output.phase = phase;
    return output;
}

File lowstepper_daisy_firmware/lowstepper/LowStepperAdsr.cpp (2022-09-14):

#include "LowStepperAdsr.h"
#include "util.h"

LowStepperAdsr::LowStepperAdsr(float sampleRate) {
  Adsr env;
  this->envelope = env;
  this->envelope.Init(sampleRate);
}

LowStepperOutput LowStepperAdsr::tick(LowStepperAdsrInput input) {
  this->envelope.SetAttackTime(input.attack);
  this->envelope.SetDecayTime(input.decay);
  this->envelope.SetSustainLevel(input.sustain);
  this->envelope.SetReleaseTime(input.release);

  float envValue = mapFFFF(
    this->envelope.Process(input.isGateHigh),
    0, 1, -0.2, 1
  );

  LowStepperOutput output = { false, envValue, 0 };
  return output;
}

float LowStepperAdsr::mapAttack(float input) {
  return mapFFFF(input, 0, 1, 0, 5);
}

float LowStepperAdsr::mapDecay(float input) {
  return mapFFFF(input, 0, 1, 0, 5);
}

float LowStepperAdsr::mapSustain(float input) {
  return input; // sustain is just 0 -> 1
}

float LowStepperAdsr::mapRelease(float input) {
  return mapFFFF(input, 0, 1, 0, 5);
}

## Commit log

2020-09-10 ISR timer
2020-11-22 the LFO fucking works, finally.
    [lowstepper_hardware.kicad_pcb, lowstepper_hardware.sch]
2020-11-23 Fix early retrig bug
    [main.cpp]
2020-12-03 Both gate ins with fixed clock divider
    [main.cpp]
2020-12-05 Morph sin -> saw -> square
    [lowstepper_hardware.kicad_pcb, lowstepper_hardware.sch]
2020-12-05 I/O schematics
    [lowstepper_hardware.kicad_pcb, lowstepper_hardware.sch]
2020-12-05 Closer to done hardware, schematics 75% there
2021-01-07 HELLO ALON
    [lowstepper_hardware.kicad_pcb, lowstepper_hardware.sch]
2021-01-12 fix for wasm build
    [ui_emscripten.h]
2021-01-14 annotate hardware
    [lowstepper_hardware.sch]
2021-01-16 Hardware annotations
    [lowstepper_hardware.sch]
2021-01-16 Remove scan CV from schematics
    [lowstepper_hardware.sch]
2021-01-16 Add EOC to pins in schematic
    [lowstepper_hardware.sch]
2021-01-17 hardware annotation / PCB placement
    [lowstepper_hardware.kicad_pcb, lowstepper_hardware.sch]
2021-01-23 Update for bhavesh
    [lowstepper_hardware.kicad_pcb, lowstepper_hardware.sch]
2021-01-23 annotate sch
    [lowstepper_hardware.sch]
2021-01-30 schematics changes
    [lowstepper_hardware.kicad_pcb, lowstepper_hardware.sch]
2021-02-01 Fixed symbol libs & port symbols. Added opamps.
    Opamp circuits for CV inputs are now encapsulated in a sub-sheet
    so that changes need to be made only once, instead of being copy
    pasta'd over and over again.
    Added correct footprint for the 2x8 pin header.
    Power port symbols are now all legit, instead of just net names.
    [CV_Input_Cct.sch, lowstepper_hardware.kicad_pcb, lowstepper_hardware.sch]
2021-02-16 Finished CV inputs, CV outputs, LED, button & decoupling
    Those changes were made in schematic. Also op-amp parts were selected.
    [CV_Input_Cct.sch, lowstepper_hardware.sch]
2021-02-22 Almost done schematic, only dig inputs left
    [CV_Input_Cct.sch, PJ398SM-12.step, lowstepper_hardware.kicad_pcb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]
2021-03-06 Added digital inputs, fixed missing footprints
    [CV_Input_Cct.sch, Digital_Input_Cct.sch, lowstepper_hardware.kicad_pcb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]
2021-03-06 Added missing LED and grounds on Teensy
    [CV_Input_Cct.sch, lowstepper_hardware.kicad_pcb, lowstepper_hardware.sch]
2021-03-17 jacks & pots layout
    [lowstepper_hardware.kicad_pcb]
2021-03-17 minor changes
    [lowstepper_hardware.kicad_pcb]
2021-03-17 more changes lol
    [lowstepper_hardware.kicad_pcb]
2021-03-24 JLCPCB test & rename footprints
    [CV_Input_Cct.sch, Digital_Input_Cct.sch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]
2021-03-26 halfway through the sandwich...
    [CV_Input_Cct.sch, Digital_Input_Cct.sch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]
2021-03-26 cu pours
    [CV_Input_Cct.sch, Digital_Input_Cct.sch, lowstepper_hardware.kicad_pcb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]
2021-03-26 JLC order attempt with the WORST layout ever
    [lowstepper_hardware-B_Cu.gbr, lowstepper_hardware-B_Mask.gbr, lowstepper_hardware-B_Paste.gbr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]
2021-05-17 Temp changes for hardware issues
    [main.cc]
2021-09-15 daisy stuff probably not gonna work
    [lowstepper_kicad.kicad_pcb, lowstepper_kicad.sch]
2021-09-16 dancers hw
    [CV_Input_Cct.sch, Digital_Input_Cct.sch, lowstepper_hardware.kicad_pcb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]
2021-12-22 Something doesn't work, but it compiles
    [LowStepperChannel.cpp, lowstepper_daisy_firmware.cpp]
2021-12-27 Daisy hardware start
    [PJ398SM-12.step, cv_in.kicad_sch, daisy_hardware_v1.kicad_pcb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]
2021-12-27 first pass of daisy schematic
    [cv_in.kicad_sch, daisy_hardware_v1.kicad_sch, gate_in.kicad_sch]
2021-12-29 Schematics coming along
    [cv_in.kicad_sch, daisy_hardware_v1.csv, gate_in.kicad_sch]
2021-12-29 Update power + add start/end to schematics
    [cv_in.kicad_sch, daisy_hardware_v1.kicad_pcb, daisy_hardware_v1.kicad_sch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]
2022-01-05 Start splitting up board
    [cv_in.kicad_sch, daisy_hardware_v1.kicad_pcb, daisy_hardware_v1.kicad_sch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]
2022-01-08 Almost done PCB
    [cv_in.kicad_sch, daisy_hardware_v1.kicad_pcb, daisy_hardware_v1.kicad_sch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]
2022-01-08 p much done bottom board
    [cv_in.kicad_sch, daisy_hardware_v1.kicad_pcb, daisy_hardware_v1.kicad_sch]
2022-01-09 Board alignment
    [daisy_hardware_v1.kicad_pcb]
2022-01-09 SPDT footprint
    [cv_in.kicad_sch, daisy_hardware_v1.kicad_pcb, daisy_hardware_v1.kicad_sch]
2022-01-13 board connectors expanded
2022-01-28 okay, JLC export time
    [daisy_hardware_v1.csv, daisy_hardware_v1.kicad_pcb, daisy_hardware_v1.kicad_sch]
2022-02-01 Sent to JLC
    [CV_Input_Cct.kicad_sch, Digital_Input_Cct.kicad_sch, daisy_hardware_v1.csv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]
2022-07-21 BIG DAY TODAY THINGS WORK
    [daisy_hardware_v1-B_Cu.gbl, daisy_hardware_v1-B_Mask.gbs, daisy_hardware_v1-B_Paste.gbp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]
2022-07-24 TFW gate out is broken in hardware
    [lowstepper_daisy_firmware.cpp]
2022-07-27 a lot of misc improvements, new hardware bugs found
    [lowstepper_daisy_firmware.cpp]
2022-07-27 Fixed all pin mappings for now...
    [LowStepperChannel.cpp, lowstepper_daisy_firmware.cpp]
2022-08-10 working without USB grounding lol
2022-08-18 Switch between fast/slow
2022-09-18 faceplate and circuit still in same progress, reviewed tho
    [daisy_hardware_v1.kicad_pcb, daisy_hardware_v1.kicad_sch]
2022-10-02 It all seems to work so far
    [daisy_hardware_v1-B_Cu.gbl, daisy_hardware_v1-B_Mask.gbs, daisy_hardware_v1-B_Paste.gbp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]
2022-10-07 Fix bottoming out bug... somehow????
    [lowstepper_daisy_firmware.cpp]
2022-11-01 another export
    [daisy_hardware_v1-B_Cu.gbl, daisy_hardware_v1-B_Mask.gbs, daisy_hardware_v1-B_Paste.gbp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]
2022-12-26 comitting code before I go in the trenches of kicad
2023-01-06 3v3a connected
    [daisy_hardware_v1.kicad_pcb, daisy_hardware_v1.kicad_sch]
2023-01-08 Last JLC hopefully
    [daisy_hardware_v1-B_Cu.gbl, daisy_hardware_v1-B_Mask.gbs, daisy_hardware_v1-B_Paste.gbp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]
2023-01-18 add little gap in CV in to make sure behaviour with no cables is more butter
2023-01-19 Fix weird bug where phases are equal + add buffer there
    [GateIn.cc]
2023-12-23 move caps JLC
    [daisy_hardware_v1.kicad_pcb]
